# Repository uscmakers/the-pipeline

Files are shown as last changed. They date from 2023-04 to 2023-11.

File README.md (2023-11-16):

# the-pipeline
Fully automated IDEX 3D printer with Slackbot support

## Canbus Setup

Create a new file in RPi /etc/network/interfaces.d/can0 with the following contents:

'''
allow-hotplug can0
iface can0 can static
    bitrate 250000
    up ifconfig $IFACE txqueuelen 128
'''

## Cura Setup

Install latest version of Cura. Then copy all json files under `cura-resources` into their respective folders in `C:\Program Files\Ultimakers Cura 5.0.0\share\cura\resources\` or where Cura keeps its config files. If you need further assistance on this step please watch this video on [how to add SOVOL SV04 Printer into Cura 5.0](https://www.youtube.com/watch?v=4KL_7jbV8KM) but use the files from this repo. You should preferably `git clone` this repo to make copying easier since there are many folders and files.

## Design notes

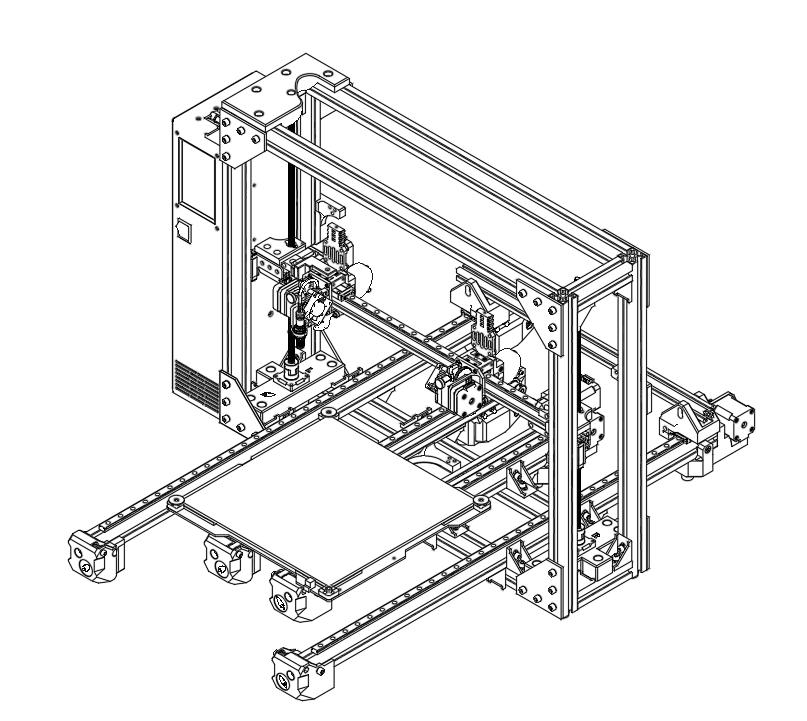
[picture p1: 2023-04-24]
misc/pipeline_home.png

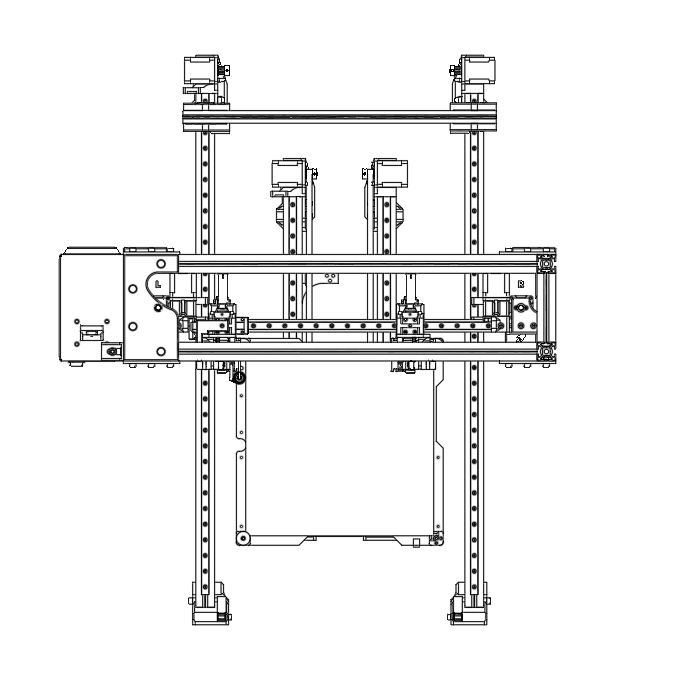
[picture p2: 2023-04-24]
misc/pipeline_topdown.png

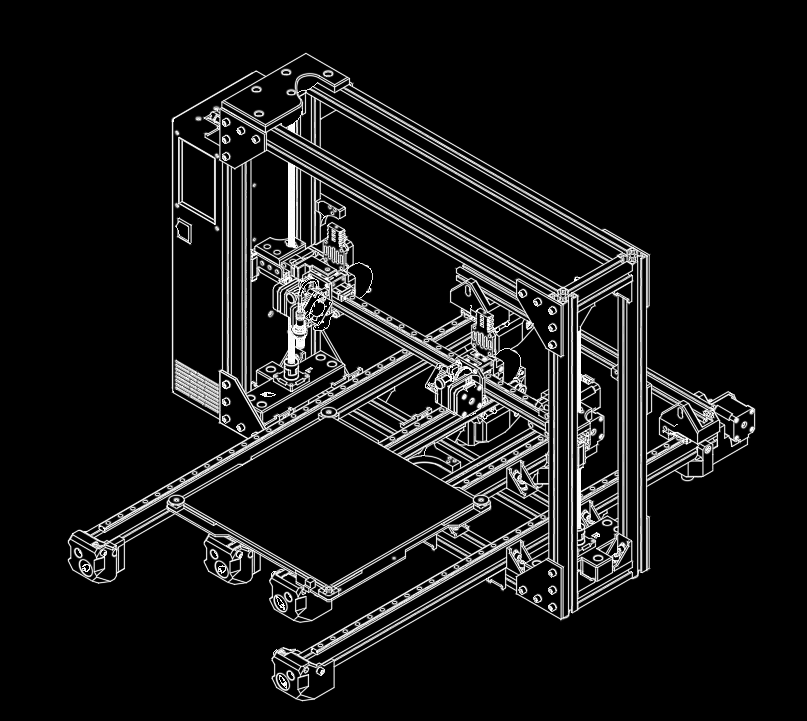
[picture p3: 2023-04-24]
misc/pipeline_inverted.png

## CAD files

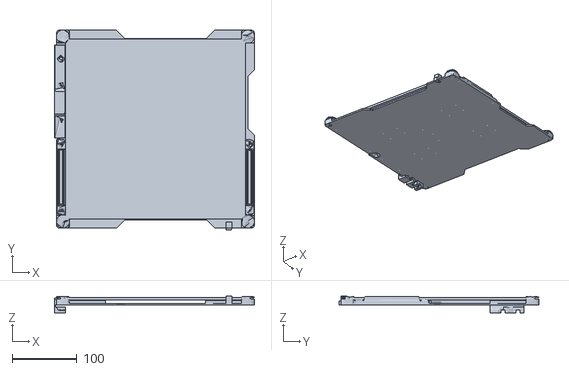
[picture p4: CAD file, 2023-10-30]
cura-resources/meshes/lulzbot_taz_pro_bed.stl
310.0 x 310.0 x 26.1

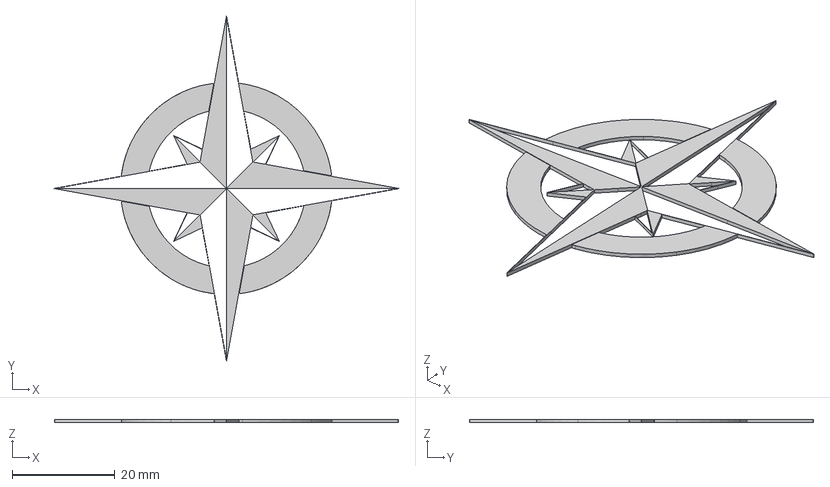
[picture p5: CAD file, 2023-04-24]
token/compass.step
66.8 x 66.8 x 0.6 mm

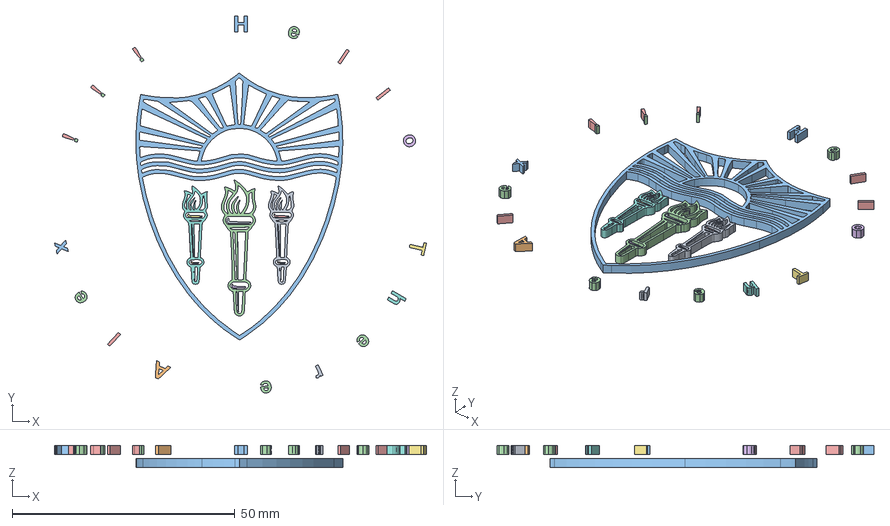
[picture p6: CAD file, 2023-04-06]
token/custom_tokens/Alex/color2.step
83.5 x 84.7 x 5.00 mm

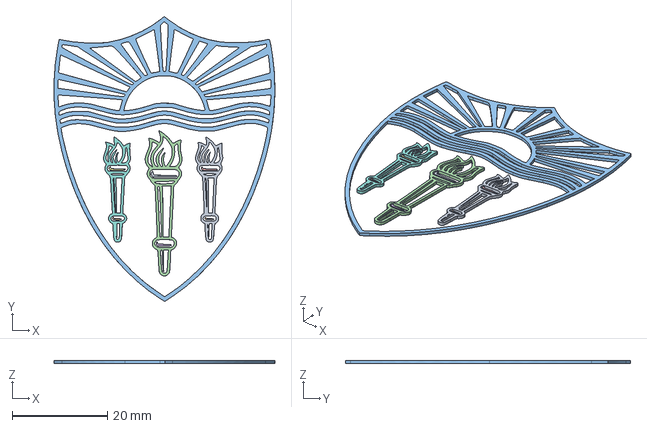
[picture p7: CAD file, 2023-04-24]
token/usclogo.step
46.5 x 60.0 x 0.6 mm

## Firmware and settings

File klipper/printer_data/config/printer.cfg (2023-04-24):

# The following configuration is built from Rat Rig V-core 3 klipper config

# The first thing you'll need to do is go through this file and comment out / uncomment 
# the files and/or settings you need.
# You'll be able to print just fine with this config as it is, but it is recommended
# that you follow these steps to properly calibrate your printer:
# 0) Sanity check and PID Tuning: https://www.klipper3d.org/Config_checks.html
# 1) Pressure Advance: https://www.klipper3d.org/Pressure_Advance.html
# 2) Skew Correction: https://www.klipper3d.org/Skew_Correction.html
# 3) Resonance Compensation: https://www.klipper3d.org/Resonance_Compensation.html

# Read more about klipper here: https://www.klipper3d.org/Overview.html

[include mainsail.cfg]
[include timelapse.cfg]

#############################################################################################################
### CONTROL BOARD
### Pick the board you have installed and wired in your printer.
#############################################################################################################
[include custom/boards.cfg]


#############################################################################################################
### BASE SETUP
#############################################################################################################
[include custom/the-pipeline.cfg]

#############################################################################################################
### STEPPER MOTORS, DRIVERS & SPEED LIMITS
### Pick the drivers and stepper motors you're using. See the RatOS documentation for custom combinations.
#############################################################################################################
[include custom/steppers.cfg]

##COOLED TMC 5160 + LDO-42STH48-2504AC
# PERFORMANCE MODE
[include custom/speed-limits-performance.cfg]
[include custom/tmc2209-performance.cfg]

#############################################################################################################
### HOMING
### Pick your probe and endstops
#############################################################################################################
[include custom/probe.cfg]

# Physical endstops
[include custom/physical-endstops.cfg]

#############################################################################################################
### INPUT SHAPER
### Enable/disable input shaper calibration
#############################################################################################################
# Uncomment this next line if you have an ADXL345 connected to your control board
# [include custom/input-shaper.cfg]


#############################################################################################################
### TOOLHEAD
### Pick your extruder and hotend
#############################################################################################################
# Extruder
[include custom/aero.cfg]

# Hotend
[include custom/v6.cfg]

#############################################################################################################
### MACROS
#############################################################################################################
[include custom/macros.cfg]
[include custom/macros_pusha.cfg]
[include custom/macros_idex.cfg]
[include custom/macros_wipers.cfg]


#############################################################################################################
### MACRO CONFIGURATION
### Configure the behavior of RatOS macros
#############################################################################################################
[gcode_macro PIPELINE]
# Use absolute extrusion mode
# Set to True to use relative extrusion mode
variable_relative_extrusion: False
# Wait for extruder to reach 150 so an inductive probe (if present) is at a predictable temp. 
# Also allows the bed heat to spread a little, and softens any plastic that might be stuck to the nozzle.
# Set to False to disable
variable_preheat_extruder: True
# Calibrate the bed mesh in the START_PRINT macro.
# Set to false to skip BED_MESH_CALIBRATE, it will still load the BED_MESH 
# with the name "ratos", be sure to save your bed_mesh profile with that name.
# or override the _START_PRINT_BED_MESH macro to implement your own mesh handling logic.
variable_calibrate_bed_mesh: True
# Print a prime line or blob at the end of the START_PRINT macro
# set to "primeline" or "primeblob", or False to disable nozzle_priming.
variable_nozzle_priming: False
# Park in the back when waiting for the extruder to heat up
# set to "front" to park in the front, or "center" to park in the center.
variable_start_print_park_in: "back"
# Height to park it when waiting for extruder to heat.
variable_start_print_park_z_height: 50
# Skew profile to load before starting the print 
# uncomment this to use your calibrated skew correction profile.
#variable_skew_profile: "my_skew_profile"
# Park in the back after the print has ended or was cancelled.
# set to "front" to park in the front, or "center" to park in the center.
variable_end_print_park_in: "back"
# Park in the back when the print is paused.
# set to "front" to park in the front, or "center" to park in the center.
variable_pause_print_park_in: "back"
# Set the speed for travel moves in RatOS Macros in mm/s.
variable_macro_travel_speed: 100


#############################################################################################################
### PRINTER CONFIGURATION
### Customize the defaults to your specific build
#############################################################################################################
[stepper_x]
dir_pin: x0_dir_pin # Add ! in front of pin name to reverse X stepper direction
position_min: -41.5
position_endstop: -41.5
position_max: 240

[dual_carriage]
dir_pin: x1_dir_pin
position_min: 35
position_endstop: 321
position_max: 321

[stepper_y]
dir_pin: !y0_dir_pin
position_min: -23
position_endstop: -23
position_max: 300

[stepper_y1]
dir_pin: !y1_dir_pin

[stepper_z]
dir_pin: !z0_dir_pin
position_min: -5
position_max: 280

[stepper_z1]
dir_pin: !z1_dir_pin

[manual_stepper stepper_pusha]
dir_pin: !p_dir_pin

# Z Probe configuration
[bltouch]
z_offset: 2.575 # Adjust this to fit your setup

[extruder]
# Check https://www.klipper3d.org/Pressure_Advance.html for pressure advance tuning.
#pressure_advance: 0.05
nozzle_diameter: 0.5 # Remember to change this if you change nozzle diameter.
dir_pin: EBB42_x0: e_dir_pin # Remove ! in front of pin name to reverse extruder direction
control: pid
pid_kp: 22.766
pid_ki: 1.459
pid_kd: 88.790

[extruder1]
# Check https://www.klipper3d.org/Pressure_Advance.html for pressure advance tuning.
#pressure_advance: 0.05
nozzle_diameter: 0.5 # Remember to change this if you change nozzle diameter.
dir_pin: !EBB42_x1: e_dir_pin # Remove ! in front of pin name to reverse extruder direction
# dir_pin: p1_dir_pin
control: pid
pid_kp: 22.766
pid_ki: 1.459
pid_kd: 88.790

# TODO: fix heater_bed
[heater_bed]
control: pid
pid_Kp: 286.02
pid_Ki: 54.55
pid_Kd: 374.9

# TODO: maybe add resonance testing in the future
# ADXL345 resonance testing configuration
# [resonance_tester]
# probe_points:
#    150,150,20 # 300mm printer

[exclude_object]

#############################################################################################################
### USER OVERRIDES
### Anything custom you want to add, or RatOS configuration you want to override, do it here.
#############################################################################################################

[printer] # accel limits override
max_accel: 1000
max_accel_to_decel: 1000

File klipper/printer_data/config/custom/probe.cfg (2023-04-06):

[bltouch]
sensor_pin: ^bltouch_sensor_pin
control_pin: bltouch_control_pin
speed: 7
pin_move_time: 0.675
sample_retract_dist: 10
stow_on_each_sample: False

pin_up_reports_not_triggered: True
pin_up_touch_mode_reports_triggered: True
x_offset: 27.87
y_offset: -45.55

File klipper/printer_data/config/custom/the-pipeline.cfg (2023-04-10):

[include ./base.cfg]

[heater_bed]
heater_pin: heater_bed_heating_pin
sensor_pin: heater_bed_sensor_pin
sensor_type: Honeywell 100K 135-104LAG-J01
min_temp: 0
max_temp: 120

# TODO: enable IDEX fan control later
# https://github.com/Klipper3d/klipper/issues/2174#issuecomment-613730313
# [fan]
# pin: EBB42_x0: fan_part_cooling_pin
# max_power: 1.0
# [fan]
# pin: EBB42_x1: fan_part_cooling_pin
# max_power: 1.0

# ! for now, treat both fans as one
[multi_pin idex_part_cooling_fan]
pins: EBB42_x0: fan_part_cooling_pin, EBB42_x1: fan_part_cooling_pin

[fan]
pin: multi_pin:idex_part_cooling_fan
max_power: 1.0

[heater_fan x0_cooling_fan]
pin: EBB42_x0: fan_toolhead_cooling_pin
heater: extruder
fan_speed: 1.0

[heater_fan x1_cooling_fan]
pin: EBB42_x1: fan_toolhead_cooling_pin
# pin: temp_fan_pin
heater: extruder1
fan_speed: 1.0

[controller_fan control_box_fan]
pin: fan_control_box_pin
fan_speed: 1.0

# These are only safeguards for first time users
# Modify printer.cfg to tune acceleration.
[printer]
kinematics: cartesian
max_velocity: 100
max_accel: 3000
max_accel_to_decel: 3000
max_z_velocity: 20
max_z_accel: 100

[bed_screws]
screw1: 10, 10
screw2: 10, 270
screw3: 240, 270
screw4: 240, 10

[bed_mesh]
horizontal_move_z: 5
mesh_min: 30,30
mesh_max:260,240
probe_count: 4,4

[z_tilt]
z_positions:
	-110, 150
	410, 150

points:
	10, 150
	240, 150
		
horizontal_move_z: 12
retries: 10
retry_tolerance: 0.01

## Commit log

2022-11-30 add klipper configuration for the pipeline
    [aero.cfg, base.cfg, boards.cfg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]
2022-12-02 complete config for demo
    [base.cfg, boards.cfg, demo.cfg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]
2023-03-26 2 color output files
    [usc.step, usclogo.step]
2023-04-06 CSV reading function on token generator
    [Token_Dummies.csv, color2.step, smalltest.csv]
2023-04-06 update pipeline printer configuration
    [aero.cfg, base.cfg, boards.cfg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]
2023-04-10 add custom z home gcode for safe homing
    [base.cfg, input-shaper.cfg, macros.cfg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]
2023-04-24 update all configuration before token production
    [aero.cfg, base.cfg, boards.cfg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]
2023-04-24 black even layers
    [compass.step]
2023-04-24 updated logo step
    [usclogo.step]
2023-04-24 made thinner and fixed compass height issue
    [compass.step]
2023-04-24 changed to odd black layers
    [compass.step, usclogo.step]
2023-10-30 Add Cura resources + Setup instructions for Pipeline
    [lulzbot_taz_pro_bed.stl]
